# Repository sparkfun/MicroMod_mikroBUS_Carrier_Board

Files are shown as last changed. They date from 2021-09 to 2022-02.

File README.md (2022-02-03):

MicroMod mikroBUS™ Carrier Board
========================================

SparkFun MicroMod mikroBUS™ Carrier Board (https://www.sparkfun.com/products/18710)

[*SparkFun MicroMod mikroBUS™ Carrier Board (DEV-18710)*](https://www.sparkfun.com/products/18710)

The SparkFun MicroMod mikroBUS Carrier Board takes advantage of the [MicroMod](https://www.sparkfun.com/micromod), [Qwiic](https://www.sparkfun.com/qwiic), and [mikroBUS™](https://www.mikroe.com/mikrobus) ecosystems and allows users to take advantage of the growing number of 7 [MicroMod processor boards](https://www.sparkfun.com/categories/tags/processor-board), 83 [Qwiic *(add-on)* boards](https://www.sparkfun.com/categories/tags/qwiic), and [1079 available](https://www.mikroe.com/click-boards) [Click boards™](https://www.sparkfun.com/categories/tags/click) *(as of September 2021)*, which equates to +51M different board combinations.

The mikroBUS socket comprises a pair of 8-pin female headers with a standardized pin configuration. The pins consist of three groups of communications pins (SPI, UART and I<sup>2</sup>C), six additional pins (PWM, Interrupt, Analog input, Reset and Chip select), and two power groups (3.3V and 5V).

_The [mikroBUS™ standard](https://www.mikroe.com/mikrobus) was developed by [MikroElektronika](https://www.mikroe.com/). Similar to our [Qwiic](https://www.sparkfun.com/qwiic) and [MicroMod](https://www.sparkfun.com/micromod) interfaces, mikroBUS™ provides a standardized connection for add-on [Click boards™](https://www.mikroe.com/click-boards) to be hooked up to a microcontroller based development board._

Repository Contents
-------------------

* **/Documentation** - Data sheets, additional product information
* **/Hardware** - Eagle design files (.brd, .sch)

Documentation
--------------

* **[Hookup Guide](https://learn.sparkfun.com/tutorials/2003)** - SparkFun MicroMod mikroBUS™ Carrier Board

Product Versions
----------------
* [DEV-18710](https://www.sparkfun.com/products/18710) -  initial release

License Information
-------------------

This product is _**open source**_! 

Please review the LICENSE.md file for license information. 

If you have any questions or concerns on licensing, please contact technical support on our [SparkFun forums](https://forum.sparkfun.com/viewforum.php?f=152).

Distributed as-is; no warranty is given.

- Your friends at SparkFun.

_<COLLABORATION CREDIT>_

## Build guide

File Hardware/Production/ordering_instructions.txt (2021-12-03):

panel size, 185x122mm
PCB thickness, 1.6mm
number of layers, 2
soldermask color, Red
silkscreen color, White
oz copper, 1oz
finish, HASL lead free
stencils, top
pcs per panel, 6
min trace width, 0.2032mm / 0.0080in
min drill size, 0.3048mm / 0.0120in

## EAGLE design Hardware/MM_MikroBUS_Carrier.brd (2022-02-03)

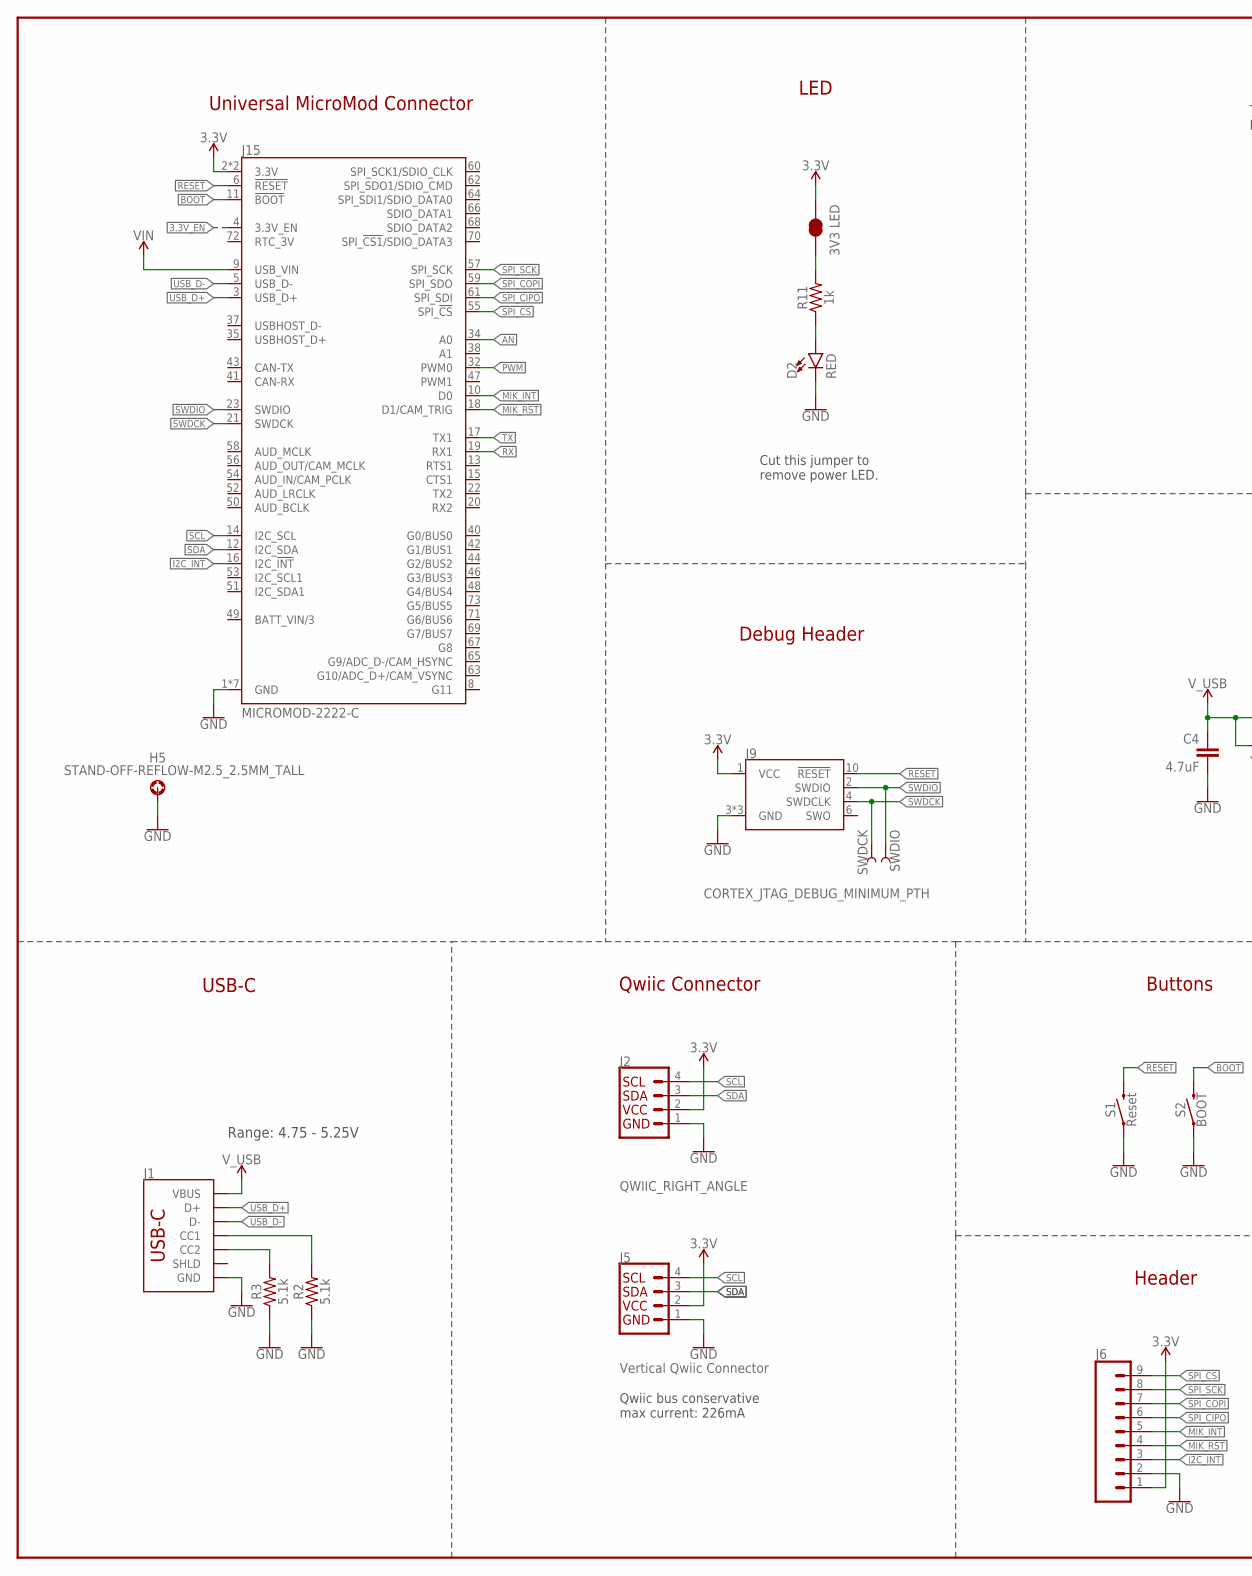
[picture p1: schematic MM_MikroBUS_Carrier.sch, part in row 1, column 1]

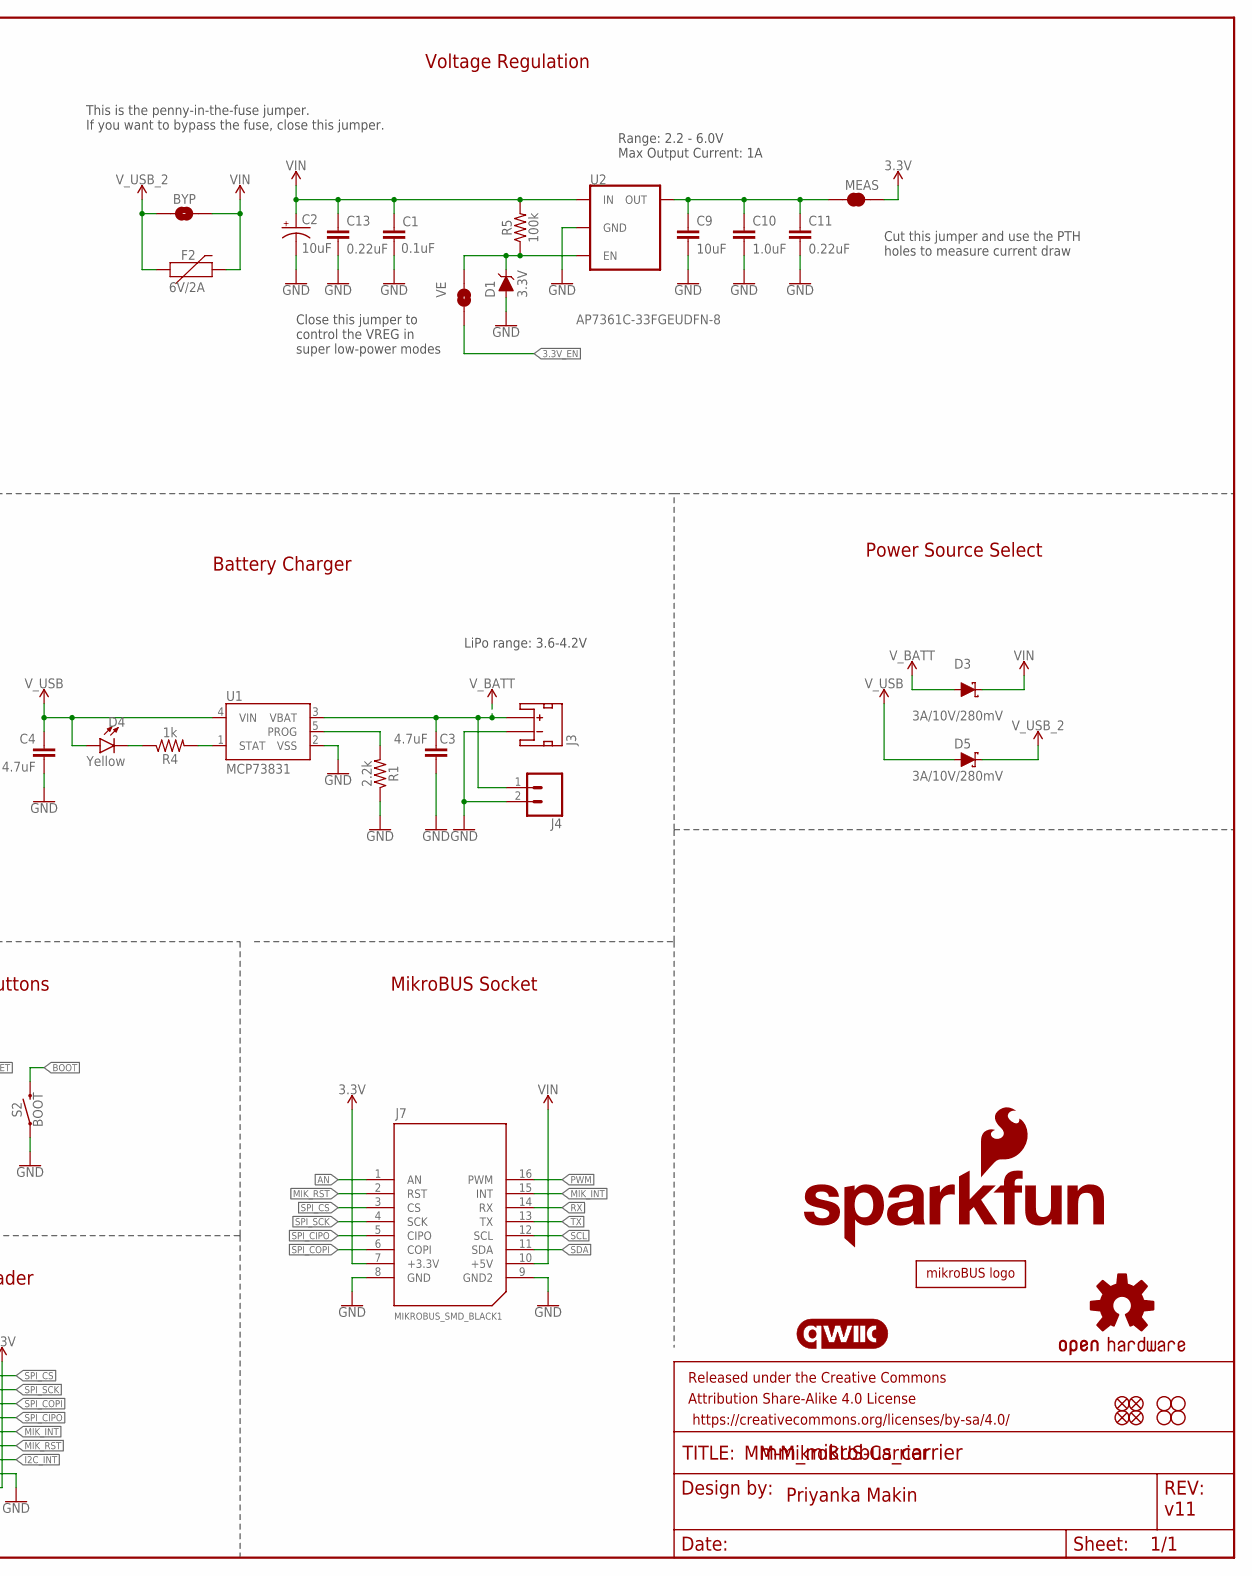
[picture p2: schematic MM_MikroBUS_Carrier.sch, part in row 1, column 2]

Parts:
BYP: JUMPER-SMT_2_NO_SILK; SMT-JUMPER_2_NO_SILK
C1: 0.1uF; 0603
C2: 10uF; EIA3216
C3, C4: 4.7uF; 0603
C9: 10uF; 0603
C10: 1.0uF; 0603
C11, C13: 0.22uF; 0603
D1: 3.3V; SOD-323
D2: RED; LED-0603
D3, D5: 3A/10V/280mV; SOD-323
D4: Yellow; LED-0603
F2: 6V/2A; 1210
FD1, FD2, FD3, FD4: FIDUCIALUFIDUCIAL; FIDUCIAL-MICRO
FRAME1: FRAME-LEDGER; CREATIVE_COMMONS
H1, H2, H3, H4: STAND-OFF
H5: STAND-OFF-REFLOW-M2.5_2.5MM_TALL; STAND-OFF-REFLOW-M2.5
J1: USB_C_2-LAYER_PADS; USB-C-16P-2LAYER-PADS
J2: QWIIC_RIGHT_ANGLE; JST04_1MM_RA
J3: JST_2MM_MALE; JST-2-SMD
J4: CONN_021X02_NO_SILK; 1X02_NO_SILK
J5: Vertical Qwiic Connector; JST04_1MM_VERT
J6: CONN_09NO_SILK; 1X09_NO_SILK
J7: MIKROBUS_SMD_BLACK1; MIKROBUS_SMD_BLACK
J9: CORTEX_JTAG_DEBUG_MINIMUM_PTH; 2X5-PTH-1.27MM
J15: MICROMOD-2222-C; M.2-CONNECTOR-E
JP4: 3V3 LED; SMT-JUMPER_2_NC_TRACE_SILK
JP6: VE; SMT-JUMPER_2_NO_SILK
LOGO1: SFE_LOGO_NAME_FLAME.2_INCH; SFE_LOGO_NAME_FLAME_.2
LOGO2: QWIIC_LOGO_CONNECTOR; QWIIC_5.5MM
LOGO3: OSHW-LOGOM; OSHW-LOGO-M
MEAS: JUMPER-COMBO_2_NC_TRACE; COMBO-JUMPER_2_NC_TRACE
R1: 2.2k; 0603
R2, R3: 5.1k; 0603
R4, R11: 1k; 0603
R5: 100k; 0603
S1: Reset; TACTILE_SWITCH_SMD_5.2MM
S2: BOOT; TACTILE_SWITCH_SMD_5.2MM
SWDCK: TEST-POINTTP_15TH_THRU; TP_15TH
SWDIO: TEST-POINTTP_15TH_THRU; TP_15TH
U1: MCP73831; SOT23-5
U2: AP7361C-33FGEUDFN-8; UDFN-8
U$7: MIKROBUS_LOGO

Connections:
3.3V: J2.2, J5.2, J6.1, J7.7 (+3.3V), J9.1 (VCC), J15.2 (3.3V), J15.74 (3.3V), JP4.2, MEAS.2, MEAS.4 (2)
3.3V_EN: J15.4 (3.3V_EN), JP6.1
!BOOT!: J15.11 (!BOOT!), S2.3 (2), S2.4 (2)
!RESET!: J9.10 (!RESET), J15.6 (!RESET!), S1.3 (2), S1.4 (2)
AN: J7.1 (AN), J15.34 (A0)
GND: C1.2, C2.-, C3.2, C4.2, C9.2, C10.2, C11.2, C13.2, D1.A, D2.C, H5.1, J1.GND, J1.GND2 (GND), J2.1, J3.1 (-), J4.2, J5.1, J6.2, J7.8 (GND), J7.9 (GND2), J9.3 (GND), J9.5 (GND), J9.9 (GND), J15.1 (GND), J15.7 (GND), J15.33 (GND), J15.36 (GND), J15.39 (GND), J15.45 (GND), J15.75 (GND), R1.1, R2.1, R3.1, S1.1, S1.2 (1), S2.1, S2.2 (1), U1.2 (VSS), U2.4 (GND), U2.EP (GND)
I2C_!INT!: J6.3, J15.16 (I2C_!INT!)
MIK_INT: J6.5, J7.15 (INT), J15.10 (D0)
MIK_RST: J6.4, J7.2 (RST), J15.18 (D1/CAM_TRIG)
unnamed: C9.1, C10.1, C11.1, MEAS.1, MEAS.3 (1), U2.1 (OUT)
unnamed: R1.2, U1.5 (PROG)
unnamed: D4.C, R4.1
unnamed: JP4.1, R11.2
unnamed: D2.A, R11.1
unnamed: R4.2, U1.1 (STAT)
unnamed: J1.A5 (CC1), R2.2
unnamed: J1.B5 (CC2), R3.2
PWM: J7.16 (PWM), J15.32 (PWM0)
RX: J7.14 (RX), J15.19 (RX1)
SCL: J2.4, J5.4, J7.12 (SCL), J15.14 (I2C_SCL)
SDA: J2.3, J5.3, J7.11 (SDA), J15.12 (I2C_SDA)
SPI_!CS!: J6.9, J7.3 (CS), J15.55 (SPI_!CS!)
SPI_CIPO: J6.6, J7.5 (CIPO), J15.61 (SPI_SDI)
SPI_COPI: J6.7, J7.6 (COPI), J15.59 (SPI_SDO)
SPI_SCK: J6.8, J7.4 (SCK), J15.57 (SPI_SCK)
SWDCK: J9.4 (SWDCLK), J15.21 (SWDCK), SWDCK.1
SWDIO: J9.2 (SWDIO), J15.23 (SWDIO), SWDIO.1
TX: J7.13 (TX), J15.17 (TX1)
USB_D+: J1.A6 (D+), J1.B6 (D+), J15.3 (USB_D+)
USB_D-: J1.A7 (D-), J1.B7 (D-), J15.5 (USB_D-)
VIN: BYP.2, C1.1, C2.+, C13.1, D3.C, F2.2, J7.10 (+5V), J15.9 (USB_VIN), R5.2, U2.8 (IN)
VREG_EN: D1.C, JP6.2, R5.1, U2.5 (EN)
V_BATT: C3.1, D3.A, J3.2 (+), J4.1, U1.3 (VBAT)
V_USB: C4.1, D4.A, D5.A, J1.VBUS1 (VBUS), J1.VBUS2 (VBUS), U1.4 (VIN)
V_USB_2: BYP.1, D5.C, F2.1

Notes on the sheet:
USB-C
Universal MicroMod Connector
Priyanka Makin
MM-MikroBUS-Carrier
LED
v11
Cut this jumper to remove power LED.
Range: 4.75 - 5.25V
Voltage Regulation
Range: 2.2 - 6.0V Max Output Current: 1A
Close this jumper to control the VREG in super low-power modes
This is the penny-in-the-fuse jumper. If you want to bypass the fuse, close this jumper.
Qwiic Connector
Buttons
Battery Charger
Power Source Select
Qwiic bus conservative max current: 226mA
Header
Cut this jumper and use the PTH holes to measure current draw
LiPo range: 3.6-4.2V
MikroBUS Socket
Debug Header

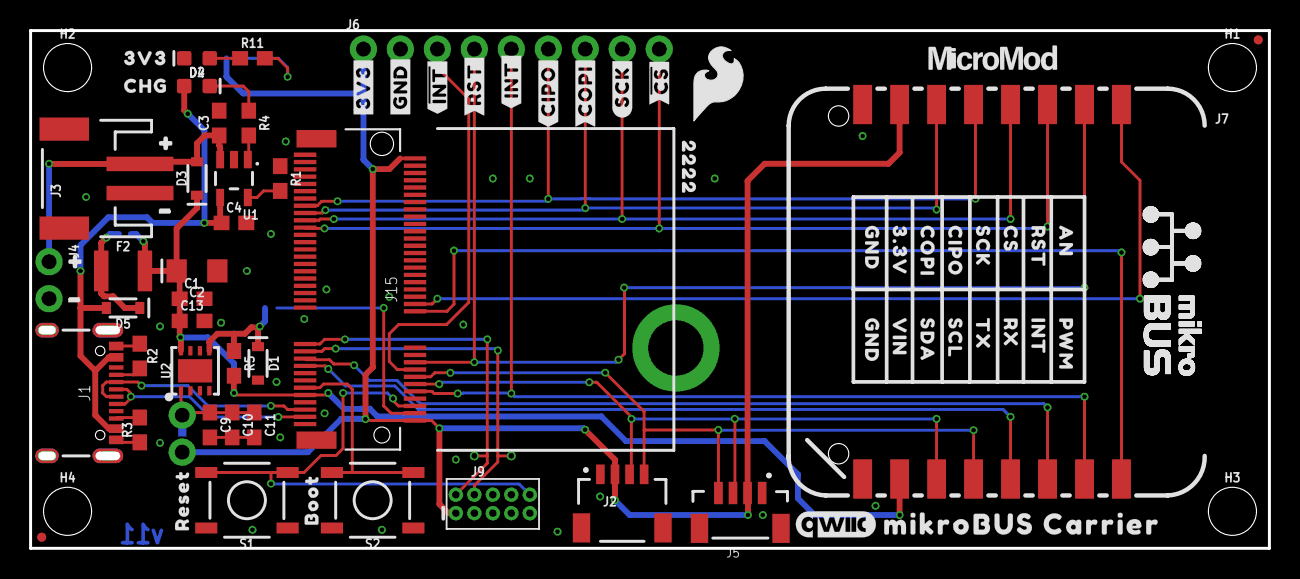
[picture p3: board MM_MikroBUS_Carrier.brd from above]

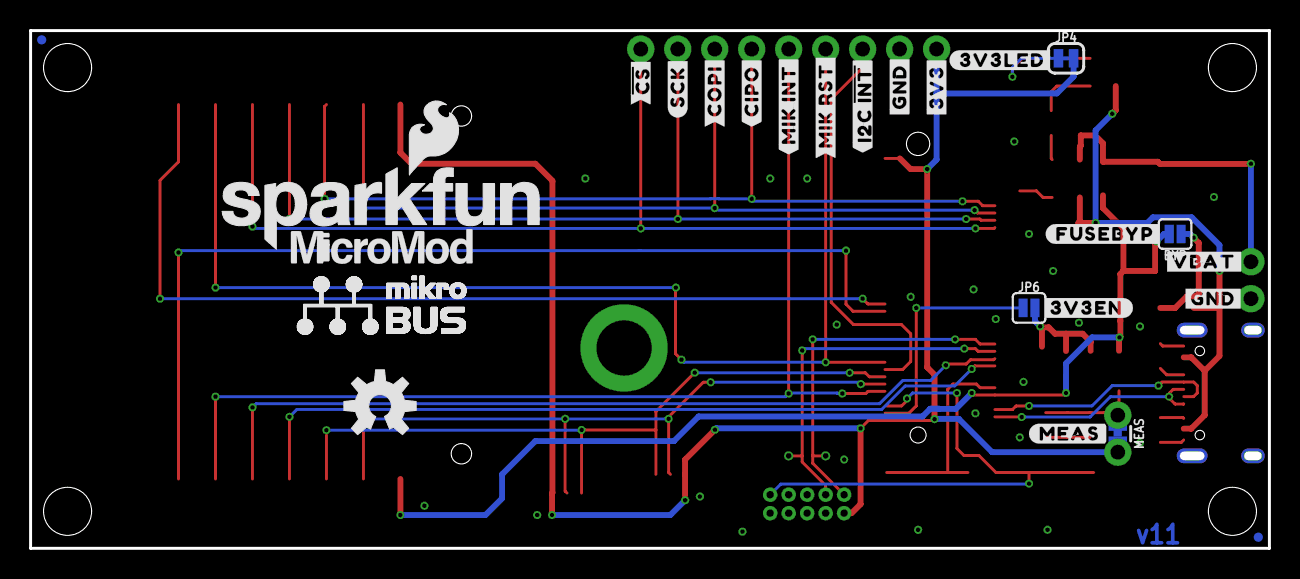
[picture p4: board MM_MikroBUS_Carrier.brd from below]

Board: 2 copper layers, 85.1 x 35.6 mm, 106 parts (25 on the bottom side), 35 nets.

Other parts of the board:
U$1: #3V3LED#0
U$2: MICROMOD_LOGO_.35
U$3: 3V30
U$4: CHG0
U$5: MIKROBUS_CARRIER0
U$6: #INT#0
U$8, U$14, U$33: #GND#0
U$9: #MEAS#0
U$10, U$13: #3V3#0
U$11, U$32, U$36, U$37: #0
U$12: #VBAT#0
U$15: ##INT##0
U$16: #MIK_INT#0
U$17: #RST#0
U$19: #MIK_RST#0
U$20: #I2C_#INT##0
U$22, U$23: #CIPO#0
U$24, U$25: #COPI#0
U$26, U$27: #SCK#0
U$28, U$29: ##CS##0
U$30: RESET0
U$31: BOOT0
U$34: 22220
U$35: AN0
U$38: #FUSEBYP#0
U$39: #3V3EN#0
U$40: RST0
U$41: CS0
U$42: SCK0
U$43: CIPO0
U$44: SFE_LOGO_FLAME_.2
U$45: COPI0
U$46: 3#3V0
U$47, U$48: GND0
U$49: PWM0
U$50: INT0
U$51: RX0
U$52: TX0
U$53: SCL0
U$54: SDA0
U$55: VIN0
U$68: MICROMOD_LOGO_.5

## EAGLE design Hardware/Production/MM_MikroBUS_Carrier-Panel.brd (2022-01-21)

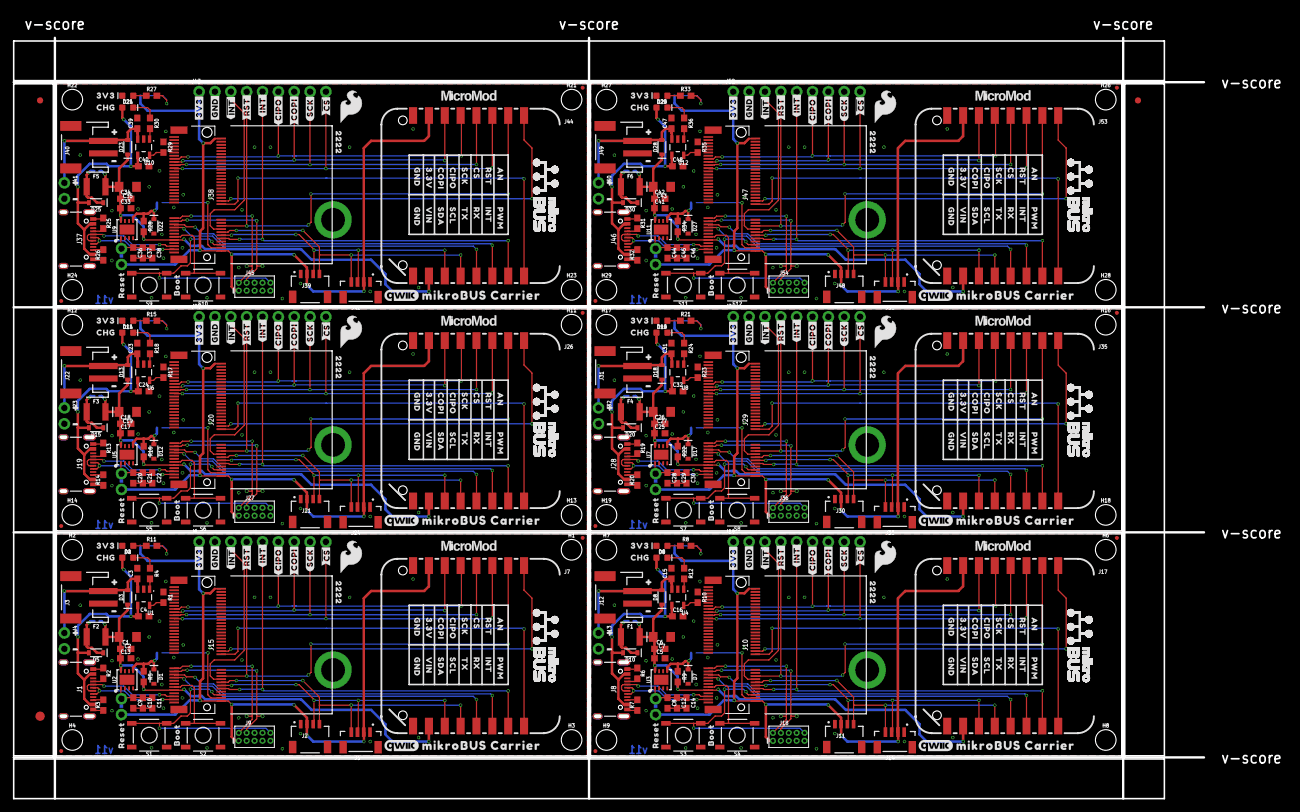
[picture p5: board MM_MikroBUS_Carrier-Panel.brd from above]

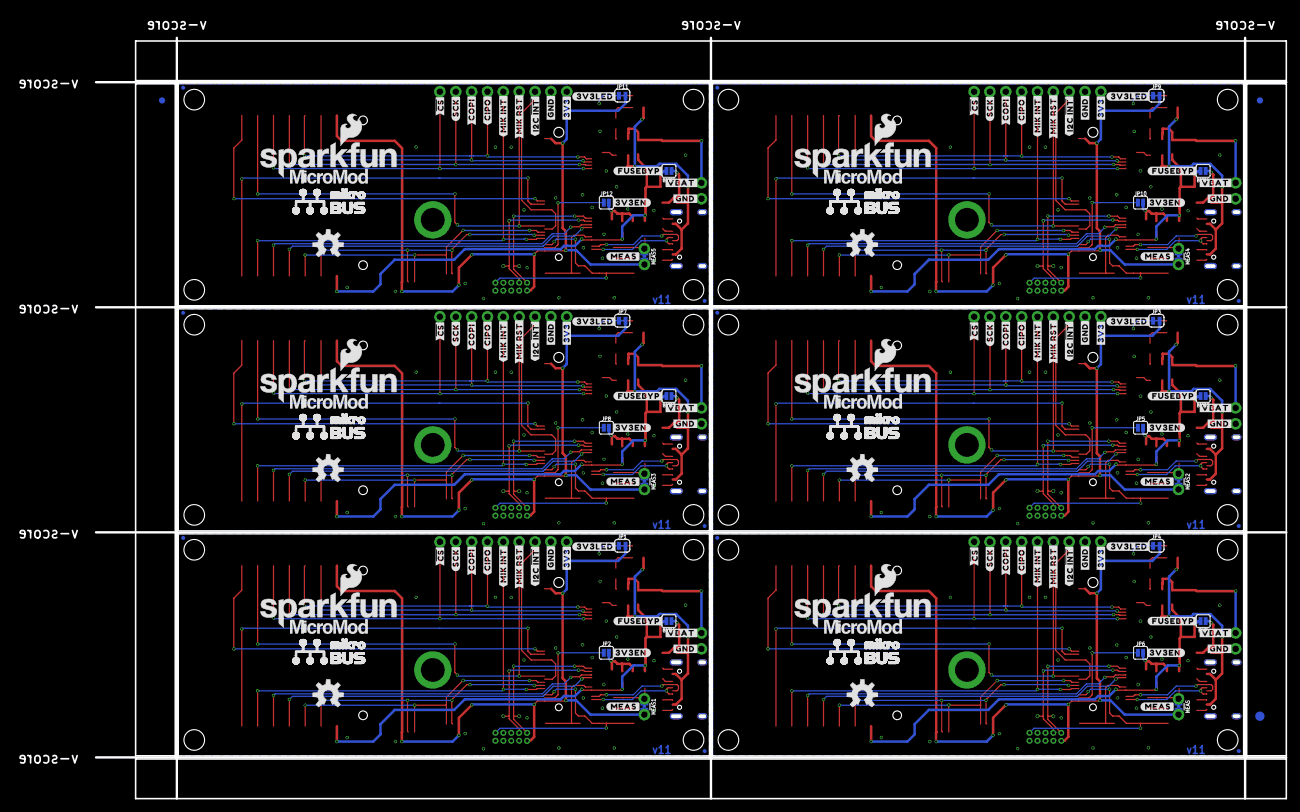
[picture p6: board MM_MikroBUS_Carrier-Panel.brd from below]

Board: 2 copper layers, 190.8 x 121.9 mm, 636 parts (153 on the bottom side), 210 nets.

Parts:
BYP, BYP1, BYP2, BYP3, BYP4, BYP5: JUMPER-SMT_2_NO_SILK; SMT-JUMPER_2_NO_SILK
C1, C6, C18, C26, C34, C42: 0.1uF; 0603
C2, C7, C19, C27, C35, C43: 10uF; EIA3216
C3, C4, C15, C16, C23, C24, C31, C32, C39, C40, C47, C48: 4.7uF; 0603
C5, C11, C13, C14, C17, C22, C25, C30, C33, C38, C41, C46: 0.22uF; 0603
C8, C9, C20, C28, C36, C44: 10uF; 0603
C10, C12, C21, C29, C37, C45: 1.0uF; 0603
D1, D7, D12, D17, D22, D27: 3.3V; SOD-323
D2, D6, D11, D16, D21, D26: RED; LED-0603
D3, D5, D8, D10, D13, D15, D18, D20, D23, D25, D28, D30: 3A/10V/280mV; SOD-323
D4, D9, D14, D19, D24, D29: Yellow; LED-0603
E$1, E$2, E$3, E$4: FIDUCIAL-1X2
E$5, E$6: FIDUCIAL-1.5X3
F1, F2, F3, F4, F5, F6: 6V/2A; 1210
FD1, FD2, FD3, FD4, FD5, FD6, FD7, FD8, FD9, FD10, FD11, FD12, FD13, FD14, FD15, FD16, FD17, FD18, FD19, FD20, FD21, FD22, FD23, FD24: FIDUCIALUFIDUCIAL; FIDUCIAL-MICRO
H1, H2, H3, H4, H6, H7, H8, H9, H11, H12, H13, H14, H16, H17, H18, H19, H21, H22, H23, H24, H26, H27, H28, H29: STAND-OFF
H5, H10, H15, H20, H25, H30: STAND-OFF-REFLOW-M2.5_2.5MM_TALL; STAND-OFF-REFLOW-M2.5
J1, J8, J19, J28, J37, J46: USB-C-16P-2LAYER-PADS
J2, J11, J21, J30, J39, J48: QWIIC_RIGHT_ANGLE; JST04_1MM_RA
J3, J12, J22, J31, J40, J49: JST-2-SMD
J4, J13, J23, J32, J41, J50: 1X02_NO_SILK
J5, J14, J24, J33, J42, J51: Vertical Qwiic Connector; JST04_1MM_VERT
J6, J16, J25, J34, J43, J52: 1X09_NO_SILK
J7, J17, J26, J35, J44, J53: MIKROBUS_SMD_BLACK1; MIKROBUS_SMD_BLACK
J9, J18, J27, J36, J45, J54: CORTEX_JTAG_DEBUG_MINIMUM_PTH; 2X5-PTH-1.27MM
J10, J15, J20, J29, J38, J47: MICROMOD-2222-C; M.2-CONNECTOR-E
JP1, JP3, JP4, JP7, JP9, JP11: 3V3 LED; SMT-JUMPER_2_NC_TRACE_SILK
JP2, JP5, JP6, JP8, JP10, JP12: VE; SMT-JUMPER_2_NO_SILK
LOGO1, LOGO6, LOGO9, LOGO12, LOGO15, LOGO18: SFE_LOGO_NAME_FLAME.2_INCH; SFE_LOGO_NAME_FLAME_.2
LOGO2, LOGO4, LOGO7, LOGO10, LOGO13, LOGO16: QWIIC_LOGO_CONNECTOR; QWIIC_5.5MM
LOGO3, LOGO5, LOGO8, LOGO11, LOGO14, LOGO17: OSHW-LOGOM; OSHW-LOGO-M
MEAS, MEAS1, MEAS2, MEAS3, MEAS4, MEAS5: JUMPER-COMBO_2_NC_TRACE; COMBO-JUMPER_2_NC_TRACE
R1, R10, R17, R23, R29, R35: 2.2k; 0603
R2, R3, R6, R7, R13, R14, R19, R20, R25, R26, R31, R32: 5.1k; 0603
R4, R8, R11, R12, R15, R18, R21, R24, R27, R30, R33, R36: 1k; 0603
R5, R9, R16, R22, R28, R34: 100k; 0603
S1, S3, S5, S7, S9, S11: Reset; TACTILE_SWITCH_SMD_5.2MM
S2, S4, S6, S8, S10, S12: BOOT; TACTILE_SWITCH_SMD_5.2MM
SWDCK, SWDCK1, SWDCK2, SWDCK3, SWDCK4, SWDCK5: TEST-POINTTP_15TH_THRU; TP_15TH
SWDIO, SWDIO1, SWDIO2, SWDIO3, SWDIO4, SWDIO5: TEST-POINTTP_15TH_THRU; TP_15TH
U1, U4, U6, U8, U10, U12: MCP73831; SOT23-5
U2, U3, U5, U7, U9, U11: AP7361C-33FGEUDFN-8; UDFN-8
U$1, U$100, U$154, U$208, U$262, U$316: #3V3LED#0
U$2, U$80, U$134, U$188, U$242, U$296: MICROMOD_LOGO_.35
U$3, U$58, U$113, U$167, U$221, U$275: 3V30
U$4, U$56, U$111, U$165, U$219, U$273: CHG0
U$5, U$83, U$137, U$191, U$245, U$299: MIKROBUS_CARRIER0
U$6, U$104, U$158, U$212, U$266, U$320: #INT#0
U$7, U$101, U$155, U$209, U$263, U$317: MIKROBUS_LOGO
U$8, U$14, U$33, U$59, U$60, U$69, U$114, U$115, U$123, U$168, U$169, U$177, U$222, U$223, U$231, U$276, U$277, U$285: #GND#0
U$9, U$57, U$112, U$166, U$220, U$274: #MEAS#0
U$10, U$13, U$81, U$82, U$135, U$136, U$189, U$190, U$243, U$244, U$297, U$298: #3V3#0
U$11, U$32, U$36, U$37, U$70, U$71, U$72, U$73, U$124, U$125, U$126, U$127, U$178, U$179, U$180, U$181, U$232, U$233, U$234, U$235, U$286, U$287, U$288, U$289: #0
U$12, U$67, U$122, U$176, U$230, U$284: #VBAT#0
U$15, U$79, U$133, U$187, U$241, U$295: ##INT##0
U$16, U$107, U$161, U$215, U$269, U$323: #MIK_INT#0
U$17, U$105, U$159, U$213, U$267, U$321: #RST#0
U$18, U$44, U$109, U$163, U$217, U$271: SFE_LOGO_FLAME_.2
U$19, U$108, U$162, U$216, U$270, U$324: #MIK_RST#0
U$20, U$106, U$160, U$214, U$268, U$322: #I2C_#INT##0
U$21, U$68, U$110, U$164, U$218, U$272: MICROMOD_LOGO_.5
U$22, U$23, U$61, U$62, U$116, U$117, U$170, U$171, U$224, U$225, U$278, U$279: #CIPO#0
U$24, U$25, U$63, U$64, U$118, U$119, U$172, U$173, U$226, U$227, U$280, U$281: #COPI#0
U$26, U$27, U$65, U$66, U$120, U$121, U$174, U$175, U$228, U$229, U$282, U$283: #SCK#0
U$28, U$29, U$77, U$78, U$131, U$132, U$185, U$186, U$239, U$240, U$293, U$294: ##CS##0
U$30, U$74, U$128, U$182, U$236, U$290: RESET0
U$31, U$75, U$129, U$183, U$237, U$291: BOOT0
U$34, U$76, U$130, U$184, U$238, U$292: 22220
U$35, U$84, U$138, U$192, U$246, U$300: AN0
U$38, U$102, U$156, U$210, U$264, U$318: #FUSEBYP#0
U$39, U$103, U$157, U$211, U$265, U$319: #3V3EN#0
U$40, U$85, U$139, U$193, U$247, U$301: RST0
U$41, U$86, U$140, U$194, U$248, U$302: CS0
U$42, U$87, U$141, U$195, U$249, U$303: SCK0
U$43, U$88, U$142, U$196, U$250, U$304: CIPO0
U$45, U$89, U$143, U$197, U$251, U$305: COPI0
U$46, U$90, U$144, U$198, U$252, U$306: 3#3V0
U$47, U$48, U$91, U$92, U$145, U$146, U$199, U$200, U$253, U$254, U$307, U$308: GND0
U$49, U$93, U$147, U$201, U$255, U$309: PWM0
U$50, U$94, U$148, U$202, U$256, U$310: INT0
U$51, U$95, U$149, U$203, U$257, U$311: RX0
U$52, U$96, U$150, U$204, U$258, U$312: TX0
U$53, U$97, U$151, U$205, U$259, U$313: SCL0
U$54, U$98, U$152, U$206, U$260, U$314: SDA0
U$55, U$99, U$153, U$207, U$261, U$315: VIN0

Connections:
3.3V: J2.2, J5.2, J6.1, J7.7, J9.1, J15.2, J15.74, JP4.2, MEAS.2, MEAS.4
3.3V1: J10.2, J10.74, J11.2, J14.2, J16.1, J17.7, J18.1, JP1.2, MEAS1.2, MEAS1.4
3.3V2: J20.2, J20.74, J21.2, J24.2, J25.1, J26.7, J27.1, JP3.2, MEAS2.2, MEAS2.4
3.3V3: J29.2, J29.74, J30.2, J33.2, J34.1, J35.7, J36.1, JP7.2, MEAS3.2, MEAS3.4
3.3V4: J38.2, J38.74, J39.2, J42.2, J43.1, J44.7, J45.1, JP9.2, MEAS4.2, MEAS4.4
3.3V5: J47.2, J47.74, J48.2, J51.2, J52.1, J53.7, J54.1, JP11.2, MEAS5.2, MEAS5.4
3.3V_EN: J15.4, JP6.1
3.3V_EN1: J10.4, JP2.1
3.3V_EN2: J20.4, JP5.1
3.3V_EN3: J29.4, JP8.1
3.3V_EN4: J38.4, JP10.1
3.3V_EN5: J47.4, JP12.1
!BOOT!: J15.11, S2.3, S2.4
!BOOT!1: J10.11, S4.3, S4.4
!BOOT!2: J20.11, S6.3, S6.4
!BOOT!3: J29.11, S8.3, S8.4
!BOOT!4: J38.11, S10.3, S10.4
!BOOT!5: J47.11, S12.3, S12.4
!RESET!: J9.10, J15.6, S1.3, S1.4
!RESET!1: J10.6, J18.10, S3.3, S3.4
!RESET!2: J20.6, J27.10, S5.3, S5.4
!RESET!3: J29.6, J36.10, S7.3, S7.4
!RESET!4: J38.6, J45.10, S9.3, S9.4
!RESET!5: J47.6, J54.10, S11.3, S11.4
AN: J7.1, J15.34
AN1: J10.34, J17.1
AN2: J20.34, J26.1
AN3: J29.34, J35.1
AN4: J38.34, J44.1
AN5: J47.34, J53.1
GND: C1.2, C2.-, C3.2, C4.2, C9.2, C10.2, C11.2, C13.2, D1.A, D2.C, H5.1, J1.GND, J1.GND2, J2.1, J3.1, J4.2, J5.1, J6.2, J7.8, J7.9, J9.3, J9.5, J9.9, J15.1, J15.7, J15.33, J15.36, J15.39, J15.45, J15.75, R1.1, R2.1, R3.1, S1.1, S1.2, S2.1, S2.2, U1.2, U2.4, U2.EP
GND1: C5.2, C6.2, C7.-, C8.2, C12.2, C14.2, C15.2, C16.2, D6.C, D7.A, H10.1, J8.GND, J8.GND2, J10.1, J10.7, J10.33, J10.36, J10.39, J10.45, J10.75, J11.1, J12.1, J13.2, J14.1, J16.2, J17.8, J17.9, J18.3, J18.5, J18.9, R6.1, R7.1, R10.1, S3.1, S3.2, S4.1, S4.2, U3.4, U3.EP, U4.2
GND2: C17.2, C18.2, C19.-, C20.2, C21.2, C22.2, C23.2, C24.2, D11.C, D12.A, H15.1, J19.GND, J19.GND2, J20.1, J20.7, J20.33, J20.36, J20.39, J20.45, J20.75, J21.1, J22.1, J23.2, J24.1, J25.2, J26.8, J26.9, J27.3, J27.5, J27.9, R13.1, R14.1, R17.1, S5.1, S5.2, S6.1, S6.2, U5.4, U5.EP, U6.2
GND3: C25.2, C26.2, C27.-, C28.2, C29.2, C30.2, C31.2, C32.2, D16.C, D17.A, H20.1, J28.GND, J28.GND2, J29.1, J29.7, J29.33, J29.36, J29.39, J29.45, J29.75, J30.1, J31.1, J32.2, J33.1, J34.2, J35.8, J35.9, J36.3, J36.5, J36.9, R19.1, R20.1, R23.1, S7.1, S7.2, S8.1, S8.2, U7.4, U7.EP, U8.2
GND4: C33.2, C34.2, C35.-, C36.2, C37.2, C38.2, C39.2, C40.2, D21.C, D22.A, H25.1, J37.GND, J37.GND2, J38.1, J38.7, J38.33, J38.36, J38.39, J38.45, J38.75, J39.1, J40.1, J41.2, J42.1, J43.2, J44.8, J44.9, J45.3, J45.5, J45.9, R25.1, R26.1, R29.1, S9.1, S9.2, S10.1, S10.2, U9.4, U9.EP, U10.2
GND5: C41.2, C42.2, C43.-, C44.2, C45.2, C46.2, C47.2, C48.2, D26.C, D27.A, H30.1, J46.GND, J46.GND2, J47.1, J47.7, J47.33, J47.36, J47.39, J47.45, J47.75, J48.1, J49.1, J50.2, J51.1, J52.2, J53.8, J53.9, J54.3, J54.5, J54.9, R31.1, R32.1, R35.1, S11.1, S11.2, S12.1, S12.2, U11.4, U11.EP, U12.2
I2C_!INT!: J6.3, J15.16
I2C_!INT!1: J10.16, J16.3
I2C_!INT!2: J20.16, J25.3
I2C_!INT!3: J29.16, J34.3
I2C_!INT!4: J38.16, J43.3
I2C_!INT!5: J47.16, J52.3
MIK_INT: J6.5, J7.15, J15.10
MIK_INT1: J10.10, J16.5, J17.15
MIK_INT2: J20.10, J25.5, J26.15
MIK_INT3: J29.10, J34.5, J35.15
MIK_INT4: J38.10, J43.5, J44.15
MIK_INT5: J47.10, J52.5, J53.15
MIK_RST: J6.4, J7.2, J15.18
MIK_RST1: J10.18, J16.4, J17.2
MIK_RST2: J20.18, J25.4, J26.2
MIK_RST3: J29.18, J34.4, J35.2
MIK_RST4: J38.18, J43.4, J44.2
MIK_RST5: J47.18, J52.4, J53.2
unnamed: C9.1, C10.1, C11.1, MEAS.1, MEAS.3, U2.1
unnamed: R1.2, U1.5
unnamed: D4.C, R4.1
unnamed: JP4.1, R11.2
unnamed: J8.A5, R6.2
unnamed: D2.A, R11.1
unnamed: J8.B5, R7.2
unnamed: R4.2, U1.1
unnamed: JP1.1, R8.2
unnamed: J1.A5, R2.2
unnamed: J1.B5, R3.2
unnamed: D6.A, R8.1
unnamed: C8.1, C12.1, C14.1, MEAS1.1, MEAS1.3, U3.1
unnamed: R10.2, U4.5
unnamed: D9.C, R12.1
unnamed: R12.2, U4.1
unnamed: J19.A5, R13.2
unnamed: J19.B5, R14.2
unnamed: JP3.1, R15.2
unnamed: D11.A, R15.1
unnamed: C20.1, C21.1, C22.1, MEAS2.1, MEAS2.3, U5.1
unnamed: R17.2, U6.5
unnamed: D14.C, R18.1
unnamed: R18.2, U6.1
unnamed: J28.A5, R19.2
unnamed: J28.B5, R20.2
unnamed: JP7.1, R21.2
unnamed: D16.A, R21.1
unnamed: C28.1, C29.1, C30.1, MEAS3.1, MEAS3.3, U7.1
unnamed: R23.2, U8.5
unnamed: D19.C, R24.1
unnamed: R24.2, U8.1
unnamed: J37.A5, R25.2
unnamed: J37.B5, R26.2
unnamed: JP9.1, R27.2
unnamed: D21.A, R27.1
unnamed: C36.1, C37.1, C38.1, MEAS4.1, MEAS4.3, U9.1
unnamed: R29.2, U10.5
unnamed: D24.C, R30.1
unnamed: R30.2, U10.1
unnamed: J46.A5, R31.2
unnamed: J46.B5, R32.2
unnamed: JP11.1, R33.2
unnamed: D26.A, R33.1
unnamed: C44.1, C45.1, C46.1, MEAS5.1, MEAS5.3, U11.1
unnamed: R35.2, U12.5
unnamed: D29.C, R36.1
unnamed: R36.2, U12.1
PWM: J7.16, J15.32
PWM1: J10.32, J17.16
PWM2: J20.32, J26.16
PWM3: J29.32, J35.16
PWM4: J38.32, J44.16
PWM5: J47.32, J53.16
RX: J7.14, J15.19
RX1: J10.19, J17.14
RX2: J20.19, J26.14
RX3: J29.19, J35.14
RX4: J38.19, J44.14
RX5: J47.19, J53.14
SCL: J2.4, J5.4, J7.12, J15.14
SCL1: J10.14, J11.4, J14.4, J17.12
SCL2: J20.14, J21.4, J24.4, J26.12
SCL3: J29.14, J30.4, J33.4, J35.12
SCL4: J38.14, J39.4, J42.4, J44.12
SCL5: J47.14, J48.4, J51.4, J53.12
SDA: J2.3, J5.3, J7.11, J15.12
SDA1: J10.12, J11.3, J14.3, J17.11
SDA2: J20.12, J21.3, J24.3, J26.11
SDA3: J29.12, J30.3, J33.3, J35.11
SDA4: J38.12, J39.3, J42.3, J44.11
SDA5: J47.12, J48.3, J51.3, J53.11
SPI_!CS!: J6.9, J7.3, J15.55
SPI_!CS!1: J10.55, J16.9, J17.3
SPI_!CS!2: J20.55, J25.9, J26.3
SPI_!CS!3: J29.55, J34.9, J35.3
SPI_!CS!4: J38.55, J43.9, J44.3
SPI_!CS!5: J47.55, J52.9, J53.3
SPI_CIPO: J6.6, J7.5, J15.61
SPI_CIPO1: J10.61, J16.6, J17.5
SPI_CIPO2: J20.61, J25.6, J26.5
SPI_CIPO3: J29.61, J34.6, J35.5
SPI_CIPO4: J38.61, J43.6, J44.5
SPI_CIPO5: J47.61, J52.6, J53.5
SPI_COPI: J6.7, J7.6, J15.59
SPI_COPI1: J10.59, J16.7, J17.6
SPI_COPI2: J20.59, J25.7, J26.6
SPI_COPI3: J29.59, J34.7, J35.6
SPI_COPI4: J38.59, J43.7, J44.6
SPI_COPI5: J47.59, J52.7, J53.6
SPI_SCK: J6.8, J7.4, J15.57
SPI_SCK1: J10.57, J16.8, J17.4
SPI_SCK2: J20.57, J25.8, J26.4
SPI_SCK3: J29.57, J34.8, J35.4
SPI_SCK4: J38.57, J43.8, J44.4
SPI_SCK5: J47.57, J52.8, J53.4
SWDCK: J9.4, J15.21, SWDCK.1
SWDCK1: J10.21, J18.4, SWDCK1.1
SWDCK2: J20.21, J27.4, SWDCK2.1
SWDCK3: J29.21, J36.4, SWDCK3.1
SWDCK4: J38.21, J45.4, SWDCK4.1
SWDCK5: J47.21, J54.4, SWDCK5.1
SWDIO: J9.2, J15.23, SWDIO.1
SWDIO1: J10.23, J18.2, SWDIO1.1
SWDIO2: J20.23, J27.2, SWDIO2.1
SWDIO3: J29.23, J36.2, SWDIO3.1
SWDIO4: J38.23, J45.2, SWDIO4.1
SWDIO5: J47.23, J54.2, SWDIO5.1
TX: J7.13, J15.17
TX1: J10.17, J17.13
TX2: J20.17, J26.13
TX3: J29.17, J35.13
TX4: J38.17, J44.13
TX5: J47.17, J53.13
USB_D+: J1.A6, J1.B6, J15.3
USB_D+1: J8.A6, J8.B6, J10.3
USB_D+2: J19.A6, J19.B6, J20.3
USB_D+3: J28.A6, J28.B6, J29.3
USB_D+4: J37.A6, J37.B6, J38.3
USB_D+5: J46.A6, J46.B6, J47.3
USB_D-: J1.A7, J1.B7, J15.5
USB_D-1: J8.A7, J8.B7, J10.5
USB_D-2: J19.A7, J19.B7, J20.5
USB_D-3: J28.A7, J28.B7, J29.5
USB_D-4: J37.A7, J37.B7, J38.5
USB_D-5: J46.A7, J46.B7, J47.5
VIN: BYP.2, C1.1, C2.+, C13.1, D3.C, F2.2, J7.10, J15.9, R5.2, U2.8
VIN1: BYP1.2, C5.1, C6.1, C7.+, D8.C, F1.2, J10.9, J17.10, R9.2, U3.8
VIN2: BYP2.2, C17.1, C18.1, C19.+, D13.C, F3.2, J20.9, J26.10, R16.2, U5.8
VIN3: BYP3.2, C25.1, C26.1, C27.+, D18.C, F4.2, J29.9, J35.10, R22.2, U7.8
VIN4: BYP4.2, C33.1, C34.1, C35.+, D23.C, F5.2, J38.9, J44.10, R28.2, U9.8
VIN5: BYP5.2, C41.1, C42.1, C43.+, D28.C, F6.2, J47.9, J53.10, R34.2, U11.8
VREG_EN: D1.C, JP6.2, R5.1, U2.5
VREG_EN1: D7.C, JP2.2, R9.1, U3.5
VREG_EN2: D12.C, JP5.2, R16.1, U5.5
VREG_EN3: D17.C, JP8.2, R22.1, U7.5
VREG_EN4: D22.C, JP10.2, R28.1, U9.5
VREG_EN5: D27.C, JP12.2, R34.1, U11.5
V_BATT: C3.1, D3.A, J3.2, J4.1, U1.3
V_BATT1: C15.1, D8.A, J12.2, J13.1, U4.3
V_BATT2: C23.1, D13.A, J22.2, J23.1, U6.3
V_BATT3: C31.1, D18.A, J31.2, J32.1, U8.3
V_BATT4: C39.1, D23.A, J40.2, J41.1, U10.3
V_BATT5: C47.1, D28.A, J49.2, J50.1, U12.3
V_USB: C4.1, D4.A, D5.A, J1.VBUS1, J1.VBUS2, U1.4
V_USB1: C16.1, D9.A, D10.A, J8.VBUS1, J8.VBUS2, U4.4
V_USB2: C24.1, D14.A, D15.A, J19.VBUS1, J19.VBUS2, U6.4
V_USB3: C32.1, D19.A, D20.A, J28.VBUS1, J28.VBUS2, U8.4
V_USB4: C40.1, D24.A, D25.A, J37.VBUS1, J37.VBUS2, U10.4
V_USB5: C48.1, D29.A, D30.A, J46.VBUS1, J46.VBUS2, U12.4
V_USB_1: BYP1.1, D10.C, F1.1
V_USB_2: BYP.1, D5.C, F2.1
V_USB_3: BYP2.1, D15.C, F3.1
V_USB_4: BYP3.1, D20.C, F4.1
V_USB_5: BYP4.1, D25.C, F5.1
V_USB_6: BYP5.1, D30.C, F6.1

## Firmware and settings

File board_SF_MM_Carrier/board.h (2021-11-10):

/****************************************************************************
**
** Copyright (C) 2021 MikroElektronika d.o.o.
** Contact: https://www.mikroe.com/contact
**
** This file is part of the mikroSDK package
**
** Commercial License Usage
**
** Licensees holding valid commercial NECTO compilers AI licenses may use this
** file in accordance with the commercial license agreement provided with the
** Software or, alternatively, in accordance with the terms contained in
** a written agreement between you and The MikroElektronika Company.
** For licensing terms and conditions see
** https://www.mikroe.com/legal/software-license-agreement.
** For further information use the contact form at
** https://www.mikroe.com/contact.
**
**
** GNU Lesser General Public License Usage
**
** Alternatively, this file may be used for
** non-commercial projects under the terms of the GNU Lesser
** General Public License version 3 as published by the Free Software
** Foundation: https://www.gnu.org/licenses/lgpl-3.0.html.
**
** The above copyright notice and this permission notice shall be
** included in all copies or substantial portions of the Software.
**
** THE SOFTWARE IS PROVIDED "AS IS", WITHOUT WARRANTY OF ANY KIND,
** OF MERCHANTABILITY, EXPRESS OR IMPLIED, INCLUDING BUT NOT LIMITED
** TO THE WARRANTIES FITNESS FOR A PARTICULAR PURPOSE AND NONINFRINGEMENT.
** IN NO EVENT SHALL THE AUTHORS OR COPYRIGHT HOLDERS BE LIABLE FOR ANY CLAIM,
** DAMAGES OR OTHER LIABILITY, WHETHER IN AN ACTION OF CONTRACT, TORT
** OR OTHERWISE, ARISING FROM, OUT OF OR IN CONNECTION WITH THE SOFTWARE
** OR THE USE OR OTHER DEALINGS IN THE SOFTWARE.
**
****************************************************************************/
/*!
 * @file  board.h
 * @brief Main board pin mapping.
 */

#include "mikrobus.h"

#ifndef _BOARD_H_
#define _BOARD_H_

#ifdef __cplusplus
extern "C"{
#endif

// Hardware revision number
#define BOARD_REV_MAJOR (1)
#define BOARD_REV_MINOR (1)

#define BOARD_NAME "SparkFun MicroMod STM32 Processor Board"

// Mapping
#define MIKROBUS_1 1
#define MIKROBUS_1_AN PC5
#define MIKROBUS_1_RST PC1
#define MIKROBUS_1_CS PC4
#define MIKROBUS_1_SCK PA5
#define MIKROBUS_1_MISO PA6
#define MIKROBUS_1_MOSI PA7
#define MIKROBUS_1_PWM PC6
#define MIKROBUS_1_INT PC0
#define MIKROBUS_1_RX PA3
#define MIKROBUS_1_TX PA2
#define MIKROBUS_1_SCL PB10
#define MIKROBUS_1_SDA PB11

#define TFT_RST HAL_PIN_NC  // Define this pin.
#define TFT_CS HAL_PIN_NC   // Define this pin.
#define TFT_D_C HAL_PIN_NC // Define this pin.
#define TFT_RD HAL_PIN_NC // Define this pin.
#define TFT_WR HAL_PIN_NC // Define this pin.
#define TFT_TE HAL_PIN_NC // Define this pin.
#define TFT_GPIO HAL_PIN_NC // Define this pin.
#define TFT_BPWM HAL_PIN_NC // Define this pin.
#define TFT_D0 HAL_PIN_NC // Define this pin.
#define TFT_D1 HAL_PIN_NC // Define this pin.
#define TFT_D2 HAL_PIN_NC // Define this pin.
#define TFT_D3 HAL_PIN_NC // Define this pin.
#define TFT_D4 HAL_PIN_NC // Define this pin.
#define TFT_D5 HAL_PIN_NC // Define this pin.
#define TFT_D6 HAL_PIN_NC // Define this pin.
#define TFT_D7 HAL_PIN_NC // If TFT data lines are 8-bits wide do not remove "HAL_PIN_NC" definition, else define this pin (e.g., "#define TFT_D7 PE7").
#define TFT_D8 HAL_PIN_NC // If TFT data lines are 8-bits wide do not remove "HAL_PIN_NC" definition, else define this pin (e.g., "#define TFT_D8 PE8").
#define TFT_D9 HAL_PIN_NC // If TFT data lines are 8-bits wide do not remove "HAL_PIN_NC" definition, else define this pin (e.g., "#define TFT_D9 PE9").
#define TFT_D10 HAL_PIN_NC // If TFT data lines are 8-bits wide do not remove "HAL_PIN_NC" definition, else define this pin (e.g., "#define TFT_D10 PE10").
#define TFT_D11 HAL_PIN_NC // If TFT data lines are 8-bits wide do not remove "HAL_PIN_NC" definition, else define this pin (e.g., "#define TFT_D11 PE11").
#define TFT_D12 HAL_PIN_NC // If TFT data lines are 8-bits wide do not remove "HAL_PIN_NC" definition, else define this pin (e.g., "#define TFT_D12 PE12").
#define TFT_D13 HAL_PIN_NC // If TFT data lines are 8-bits wide do not remove "HAL_PIN_NC" definition, else define this pin (e.g., "#define TFT_D13 PE13").
#define TFT_D14 HAL_PIN_NC // If TFT data lines are 8-bits wide do not remove "HAL_PIN_NC" definition, else define this pin (e.g., "#define TFT_D14 PE14").
#define TFT_D15 HAL_PIN_NC // If TFT data lines are 8-bits wide do not remove "HAL_PIN_NC" definition, else define this pin (e.g., "#define TFT_D15 PE15").

#define TFT_8BIT_DATA_PORT_CH0 HAL_PORT_NC // Define this port (e.g., "#define TFT_8BIT_DATA_PORT_CH0 PORT_E").
#define TFT_8BIT_DATA_PORT_CH0_MASK 0x0000 // Define mask for this port (e.g., "#define TFT_8BIT_DATA_PORT_CH0_MASK 0x00FF").
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

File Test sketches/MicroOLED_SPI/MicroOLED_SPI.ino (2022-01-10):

/******************************************************************************
  MicroOLED_Hello.ino
  SFE_MicroOLED Hello World Demo
  Jim Lindblom @ SparkFun Electronics
  Original Creation Date: October 26, 2014
  
  This sketch lights up a familiar pattern on the MicroOLED
  Breakout. It's a great way to prove you've connected everything
  correctly and that your display is in working order.
  
  Hardware Connections:
    We'll be using the SPI interface on the MicroOLED, though it
    also supports I2C (and a really messy parallel). If you want
    to swap in I2C, read through the comments to find out how.
    
    MicroOLED ------------- Arduino
      GND ------------------- GND
      VDD ------------------- 3.3V (VCC)
    D1/MOSI ----------------- D11 (don't change)
    D0/SCK ------------------ D13 (don't change)
      D2
      D/C ------------------- D8 (can be any digital pin)
      RST ------------------- D9 (can be any digital pin)
      CS  ------------------- D10 (can be any digital pin)
    
  Development environment specifics:
  	IDE: Arduino 1.0.5
  	Hardware Platform: MicroOLED Breakout
                           Arduino Pro 3.3V/8MHz
  
  Note: The display on the MicroOLED is a 1.8V-3.3V device only.
  Don't try to connect a 5V Arduino directly to it! Use level
  shifters in between the data signals if you have to resort to
  a 5V board.
  
  This code is beerware; if you see me (or any other SparkFun 
  employee) at the local, and you've found our code helpful, 
  please buy us a round!
  
  Distributed as-is; no warranty is given.
*******************************************************************************/
#include <Wire.h>  // Include Wire if you're using I2C
#include <SPI.h>  // Include SPI if you're using SPI
#include <SFE_MicroOLED.h>  // Include the SFE_MicroOLED library

//////////////////////////
// MicroOLED Definition //
//////////////////////////
#define PIN_RESET D1  // Connect RST to pin RST on the mikroBUS socket
#define PIN_DC    D0  // Connect DC to pin INT on the mikroBUS socket
#define PIN_CS    D29 // Connect CS to pin CS on the mikroBUS socket
#define DC_JUMPER 0 // Set to either 0 (default) or 1 based on jumper, matching the value of the DC Jumper
// Also connect pin 13 to SCK and pin 11 to MOSI

//////////////////////////////////
// MicroOLED Object Declaration //
//////////////////////////////////
// Declare a MicroOLED object. The parameters include:
// 1 - Reset pin: Any digital pin
// 2 - D/C pin: Any digital pin (SPI mode only)
// 3 - CS pin: Any digital pin (SPI mode only, 10 recommended)

MicroOLED oled(PIN_RESET, PIN_DC, PIN_CS); //Example SPI declaration, comment out if using I2C
//MicroOLED oled(PIN_RESET, DC_JUMPER); //Example I2C declaration, uncomment if using I2C 

// I2C is great, but will result in a much slower update rate. The
// slower framerate may be a worthwhile tradeoff, if you need more
// pins, though.
void setup()
{

  delay(100);
  //Wire.begin(); //set up I2C bus, uncomment if you are using I2C
  // These three lines of code are all you need to initialize the
  // OLED and print the splash screen.
  
  // Before you can start using the OLED, call begin() to init
  // all of the pins and configure the OLED.
  oled.begin();
  // clear(ALL) will clear out the OLED's graphic memory.
  // clear(PAGE) will clear the Arduino's display buffer.
  oled.clear(ALL);  // Clear the display's memory (gets rid of artifacts)
  // To actually draw anything on the display, you must call the
  // display() function. 
  oled.display();   
}

void loop()
{
}

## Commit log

2021-09-14 Initial commit
    Starting with the MicroMod Qwiic Carrier - Single files.
    [MM-Qwiic-Carrier-Single.brd, MM-Qwiic-Carrier-Single.sch]
2021-09-14 Renamed eagle files
    [MM_MikroElektronika_Carrier.brd, MM_MikroElektronika_Carrier.sch]
2021-09-16 Working on proto
    [MM_MikroBUS_Carrier.brd, MM_MikroBUS_Carrier.sch]
2021-09-16 Finished proto design
    [MM_MikroBUS_Carrier.brd, MM_MikroBUS_Carrier.sch]
2021-09-20 Updates from proto design review
    MikroBUS device:
    * add pin numbers back into sch symbol
    * label with a "J" prefix
    * Center anchor/origin
    * Remove internal pin labels
    Schematic:
    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
    [MM_MikroBUS_Carrier.brd, MM_MikroBUS_Carrier.sch]
2021-09-21 Proto checklist
    Updated silkscreen and measures
    [MM_MikroBUS_Carrier.brd, MM_MikroBUS_Carrier.sch]
2021-09-21 Update schematic
    [MM_MikroBUS_Carrier.brd, MM_MikroBUS_Carrier.sch]
2021-09-22 Approve errors
    [MM_MikroBUS_Carrier.brd]
2021-09-23 Add prod-id to mikroBUS socket
    [MM_MikroBUS_Carrier.brd, MM_MikroBUS_Carrier.sch]
2021-09-23 Update name and value of mikroBUS socket and generate gerbers
    [MM_MikroBUS_Carrier.GBL, MM_MikroBUS_Carrier.GBO, MM_MikroBUS_Carrier.GBP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]
2021-10-28 Add HW test sketch
    [MM_MikroBUS_Carrier.brd]
2021-10-28 Updating with mikroE suggestions
    * "mikroBUS" label, not "MikroBUS"
    * Add pin names to socket
    * Change button labeling to "Mikroe Reset"
    [MM_MikroBUS_Carrier.brd]
2021-11-10 Updates to board.h file
2021-12-01 MikroE updates
    * Add JTAG connector
    * Remove mikroE reset button
    * Moved mikroBUS labels so that they can all be seen when socket is populated
    [MM_MikroBUS_Carrier.brd, MM_MikroBUS_Carrier.sch]
2021-12-01 Pete's updates
    * Bump version number on schematic and board
    * Add measures for header
    * Add test points for SWDIO and SWDCK
    [MM_MikroBUS_Carrier.brd, MM_MikroBUS_Carrier.sch]
2021-12-01 Pete's updates:
    * LED jumper label became "3V3LED"
    * fuse jumper label became "FUSE_BYP"
    [MM_MikroBUS_Carrier.brd]
2021-12-02 Design review updates:
    * Put mikroBUS pin labels into the table
    * Add y-measure for mikroBUS socket
    * Add mikroBUS logo to library and to the back of the board
    * Add GND vias
    [MM_MikroBUS_Carrier.brd, MM_MikroBUS_Carrier.sch]
2021-12-02 Design review updates
    * Add direction to the SPI header labels
    * Remove underscores from labels
    [MM_MikroBUS_Carrier.brd]
2021-12-02 QC double-check
    [MM_MikroBUS_Carrier.brd]
2021-12-03 Add more measures
    [MM_MikroBUS_Carrier.brd]
2021-12-03 Panelize and generate gerbers
    [MM_MikroBUS_Carrier-Panel.GBL, MM_MikroBUS_Carrier-Panel.GBO, MM_MikroBUS_Carrier-Panel.GBP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]
2022-01-21 v11 - switch RX and TX to match mikroBUS standard.
    [MM_MikroBUS_Carrier.brd, MM_MikroBUS_Carrier.sch]
2022-01-21 Re-panelize and generate new gerbers for v11
    [MM_MikroBUS_Carrier-Panel.brd, MM_MikroBUS_Carrier.brd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]
2022-01-25 Update MM_MikroBUS_Carrier.brd
    Add dimensions
    [MM_MikroBUS_Carrier.brd]
2022-01-25 Update MM_MikroBUS_Carrier.brd
    Move text to clear measurements areas
    [MM_MikroBUS_Carrier.brd]

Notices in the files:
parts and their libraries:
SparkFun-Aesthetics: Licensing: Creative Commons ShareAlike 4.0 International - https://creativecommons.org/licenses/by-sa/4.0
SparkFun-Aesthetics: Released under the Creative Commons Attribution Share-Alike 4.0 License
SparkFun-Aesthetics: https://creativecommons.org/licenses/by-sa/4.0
